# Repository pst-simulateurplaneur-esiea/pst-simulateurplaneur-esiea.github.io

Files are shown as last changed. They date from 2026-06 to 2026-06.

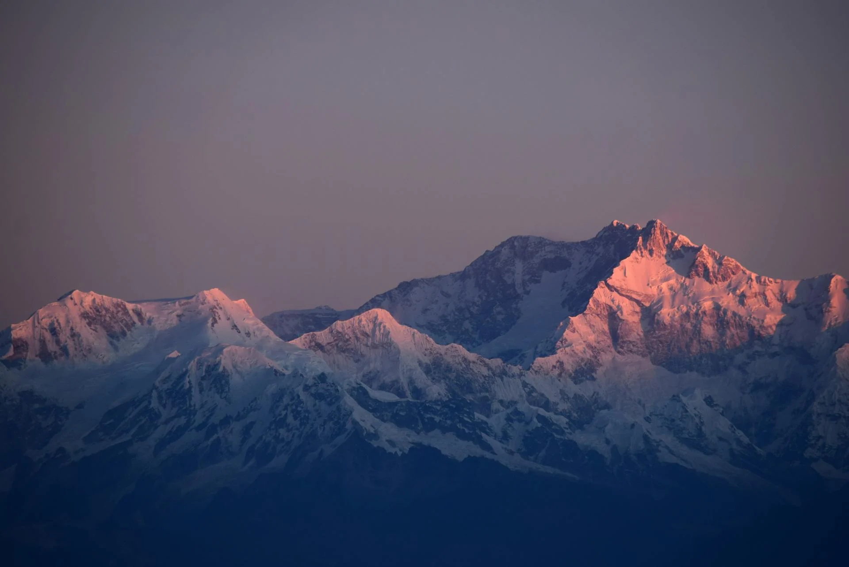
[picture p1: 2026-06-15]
image/mountain_image.jpg

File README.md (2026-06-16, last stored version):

# Glider Project Website

This is a simple, beginner-friendly website featuring a parallax scrolling effect and documentation sections.

## Files Included

- **index.html** - The main HTML structure of the website
- **style.css** - All the styling and visual design
- **script.js** - JavaScript code for the parallax scrolling effect
- **README.md** - This documentation file

## Setup Instructions

### 1. Prepare Your Images

You need to add two images to the same folder as these files:

- **glider_image.png** - Image of the glider (transparent background recommended)
- **mountain_image.jpg** - Mountain landscape for the background

**Important:** Make sure these image files are in the same directory as `index.html`.

### 2. Open the Website

Simply double-click on `index.html` to open it in your web browser.

## How It Works

### HTML Structure (index.html)

The HTML file is organized into sections:

1. **Parallax Section** - Contains the mountain background and glider image
2. **Description Section** - Project overview with black background
3. **Documentation Categories** - Two columns for different documentation types
4. **Footer** - Copyright information

### CSS Styling (style.css)

The CSS file includes:

- **General Styles** - Basic reset and font settings
- **Parallax Styles** - Positioning for the parallax layers
- **Content Styles** - Black background and text styling
- **Documentation Cards** - Styled boxes for each category
- **Responsive Design** - Mobile-friendly adjustments

### JavaScript (script.js)

The JavaScript creates the parallax effect by:

1. Listening for scroll events
2. Moving the background slower than the foreground
3. Creating a depth illusion

**Key concept:** The background moves at 50% scroll speed, while the foreground moves at 80% speed.

## Customization Guide

### Changing Colors

In `style.css`, look for these sections:

- **Background color:** `.main-content { background-color: #000000; }`
- **Card colors:** `.doc-category { background-color: #1a1a1a; }`
- **Header gradient:** `.category-header { background: linear-gradient(...) }`

### Changing Text

Open `index.html` and edit the text between the HTML tags:

```html
<h2>About the Project</h2>
<p>Your new text here</p>
```

### Adjusting Parallax Speed

In `script.js`, change these values:

```javascript
let backgroundMove = scrollPosition * 0.5;  // Lower = slower
let foregroundMove = scrollPosition * 0.8;   // Higher = faster
```

### Adding More Documentation Items

In `index.html`, copy and paste this structure within a category:

```html
<li>
    <h4>New Item Title</h4>
    <p>Description of the new item</p>
</li>
```

## Browser Compatibility

This website works on:
- Chrome, Firefox, Edge (latest versions)
- Safari (latest version)
- Mobile browsers

## Troubleshooting

**Problem:** Images don't show up
- **Solution:** Make sure image files are in the same folder as `index.html`
- Check that filenames match exactly: `glider_image.png` and `mountain_image.jpg`

**Problem:** Parallax effect doesn't work
- **Solution:** Make sure `script.js` is in the same folder and the filename is correct

**Problem:** Website looks broken
- **Solution:** Ensure `style.css` is in the same folder as `index.html`

## Tips for Beginners

1. **Use a text editor:** Visual Studio Code, Notepad++, or even Notepad
2. **Refresh the browser:** Press F5 or Ctrl+F5 to see changes
3. **Use browser DevTools:** Press F12 to inspect elements and debug
4. **Make backups:** Copy files before making major changes
5. **Test on different screens:** Check how it looks on mobile and desktop

## Understanding the Code

### What is Parallax?

Parallax is when objects move at different speeds to create a 3D depth effect. It's like looking out a car window - nearby trees move fast, distant mountains move slowly.

### How CSS Works

CSS uses selectors to target HTML elements:
- **Class selector:** `.parallax-container` (matches class="parallax-container")
- **ID selector:** `#background-layer` (matches id="background-layer")
- **Element selector:** `body` (matches all <body> tags)

### How JavaScript Works

JavaScript listens for events (like scrolling) and changes the webpage:
1. `window.addEventListener('scroll', ...)` - Watch for scrolling
2. `window.pageYOffset` - Get scroll position
3. `element.style.transform` - Move elements

## Next Steps

- Add more content to the documentation sections
- Include actual documentation links or downloads
- Add a navigation menu
- Include contact information
- Optimize images for faster loading

## License

Feel free to use and modify this code for your projects!

---

**Created:** 2026
**For:** Glider Project Documentation

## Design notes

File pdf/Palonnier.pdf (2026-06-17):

Palonnier

Équipe simulateur de planeur 2025 / 2026 | 1

# Palonnier

# Équipe PST2A 2025/2026 :

### Enzo CAFFIER Hugo LORMIER Rose NÉDÉLEC Jérémie OQUIDAM Cléo SAM-LOCK

Le Palonnier acheté et démonté : T.FLIGHT RUDDER PEDALS de ThrustMaster.

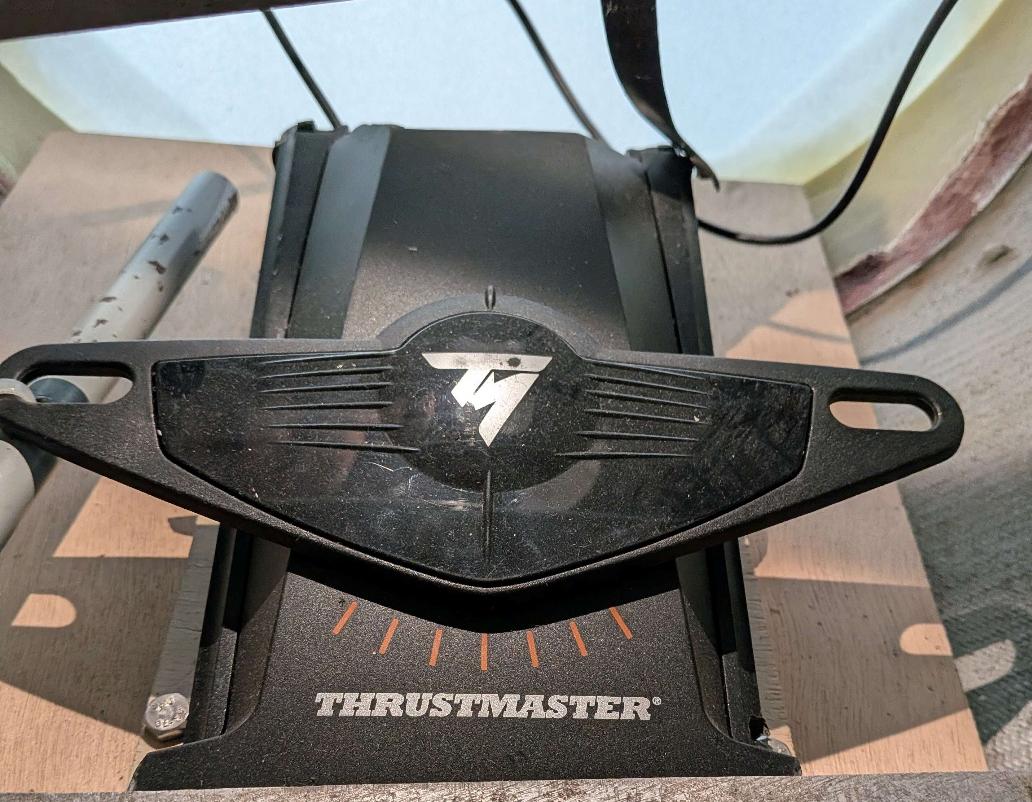
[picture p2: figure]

Ce palonnier électronique branché au hub USB dans le planeur et directement relié grâce à un tube en métal récupéré dans le planeur (en jaune) a été fixé grâce 4 vis sur une planche en bois (récupérée à l’openlab) elle-même posée sur une planche ne bois soutenue par du câble en métal accroché au planeur. Ce système est un prototype et est voué à être amélioré, un meilleur support, un système plus résistant et précis.
Ce tube en métal est directement relié et accroché au palonnier d’origine du cockpit du planeur afin de reproduire et retransmettre les mouvements des pédales du palonnier dans le palonnier électronique. Cette transmission des pédales aux palonniers est effectuée grâce aux deux câbles comme montré si dessous. Ces câbles passent dans tout le planeur jusqu’aux pédales.

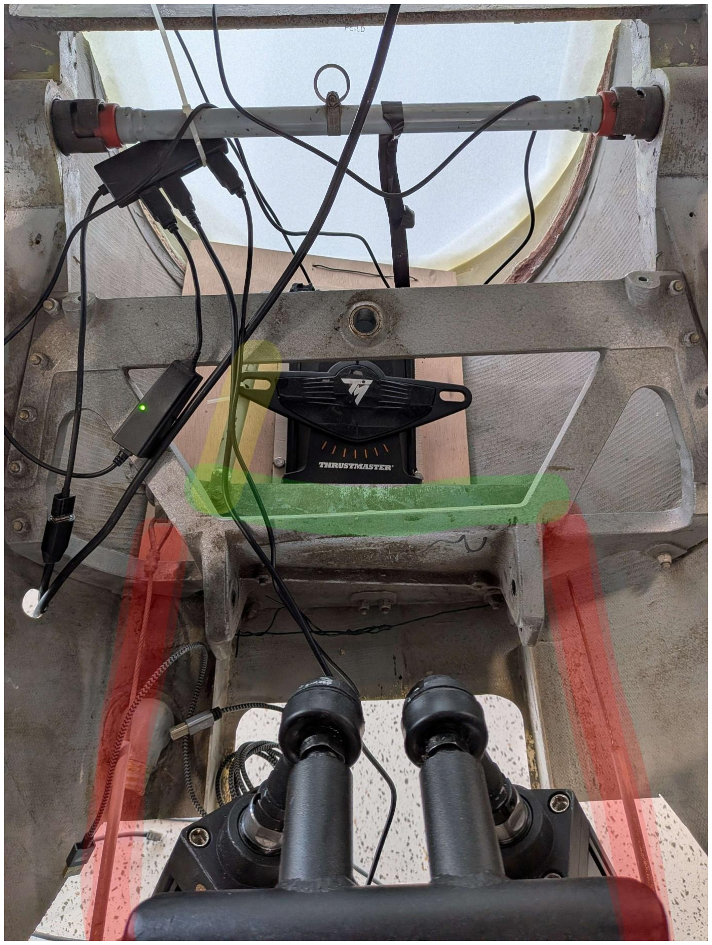
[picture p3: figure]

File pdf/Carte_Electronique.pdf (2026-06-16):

Carte_Electronique

Équipe simulateur de planeur 2025 / 2026 | 1

# Carte_Electronique

# Équipe PST2A 2025/2026 :

### Enzo CAFFIER Hugo LORMIER Rose NÉDÉLEC Jérémie OQUIDAM Cléo SAM-LOCK

La carte électronique a été récupéré sur un joystick thrustmaster TFlight Stick X qui a été démonté.

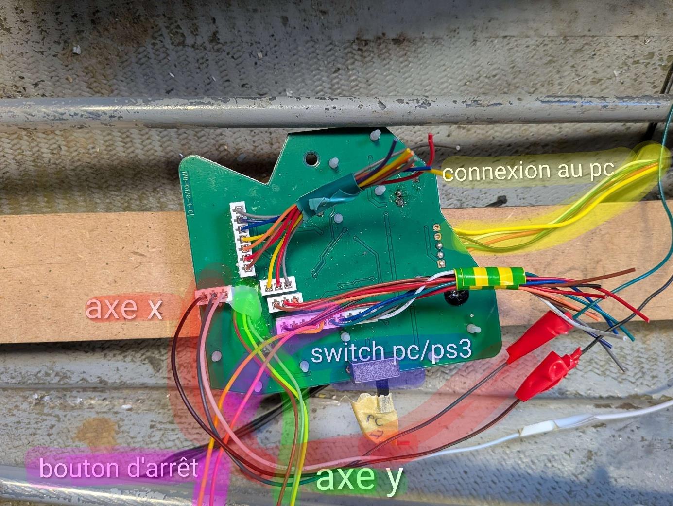
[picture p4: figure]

Le port de l’axe X :
- Cable noir : VCC+
- Cable vert : Information de -1 à 1
- Cable blanc : Terre

Le port axe Y :
- Cable rouge : VCC+
- Cable jaune : Information de -1 à 1
- Cable gris : Terre

Bouton d’arrêt, fonctionne comme un bouton d’arrêt, courant pas courant, branché aux câbles orange et jaune.
Les trois câbles précédent noir marron et rouge permettent aussi de rajouter des boutons. Le reste des pins servent pour un ancien potentiomètre (voir la photo et le composant pour plus de détails).

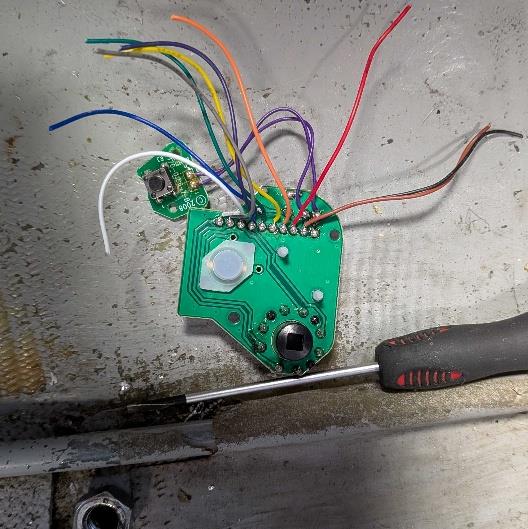
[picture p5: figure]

Switch pc/ps3 à ne pas changer afin que la carte reste compatible avec l’ordinateur branché. Switch à droite = PC, switch à gauche = PS3 : voir photo.
Sur les câbles entourés par le scotch vert, les pins sont utilisés pour des boutons en parallèles et une LED.
Câble gris : VCC+ (doit être branché)
Câbles violet, rouge, orange et marron : Boutons
Câbles jaune et bleu : permettent de brancher une LED

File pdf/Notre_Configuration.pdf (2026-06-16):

Créer configuration Flypt Mover 3.5

Équipe simulateur de planeur 2025 / 2026 | 1

# Notre configuration

# Équipe PST2A 2025/2026 :

### Enzo CAFFIER Hugo LORMIER Rose NÉDÉLEC Jérémie OQUIDAM Cléo SAM-LOCK

Pour réaliser notre configuration nous avons tout d’abord suivi les recommandations sur le site de FlyPt Mover :

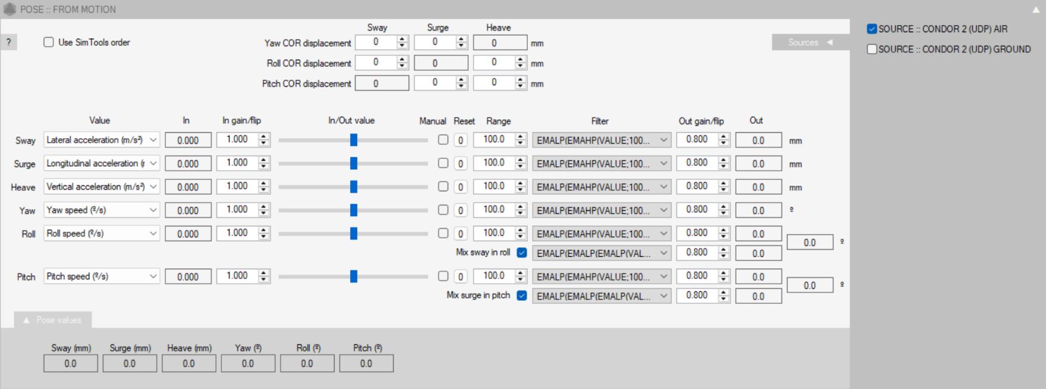
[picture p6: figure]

Pour la valeur des samples dans les filtres nous avons sélectionner les valeurs rendant un meilleur résultat après plusieurs tests, n’existant pas de formules directement disponibles pour calculer le nombre de samples optimal il est donc compliqué de justifier notre choix de manière calculatoire. Il est donc possible, voire conseillé, de trouver de meilleures valeurs à l’aide d’expériences ou de formules non disponibles actuellement.
Ainsi actuellement les filtrages sont :
Sway : emalp(emahp(VALUE,1000),300)
Surge : emalp(emahp(VALUE,1000),300) Heave : emalp(emahp(VALUE,1000),300)
Yaw : emalp(emahp(VALUE,1000),300)
Roll : emalp(emahp(VALUE,1000),300)
Mix sway in roll : emalp(emalp(emalp(value,500),500),500) Pitch : emalp(emahp(VALUE,1000),300)
Mix surge in pitch : emalp(emalp(emalp(value,500),500),500)

Cette configuration malgré son bon fonctionnement est assez vorace en terme de calculs ce qui peut causer un certain délai qui bien que minime reste dérangeant pour le pilot pouvant causer des désagréments (nausées dues à un décalage de perception entre l’oreille interne et la vision). Ce problème peut néanmoins être pallier par un ordinateur possédant une meilleure capacité de calcul.

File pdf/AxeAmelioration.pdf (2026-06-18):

Axe d’amélioration et futur du projet x

Équipe simulateur de planeur 2025 / 2026 | 1

# Axe d’amélioration et futur du projet

# Équipe PST2A 2025/2026 :

### Enzo CAFFIER Hugo LORMIER Rose NÉDÉLEC Jérémie OQUIDAM Cléo SAM-LOCK

Faire un simulateur de planeur réaliste est un magnifique projet qui reste cependant très ambitieux et compliqué à finaliser dans sa totalité en une année par des étudiants en 2eme année de cycle préparatoire. C’est donc sans surprise qu’il est facile de remarquer le manque de certaines parties au planeur, que ce soit au niveau de l’esthétisme ou à un niveau technique. En réalité ce projet n’étant pas un projet professionnel mais un projet étudiant, il reste un projet en constante évolution et amélioration. Cette section présente donc des idées dont il ne faut pas hésiter à s’inspirer mais qui ne sont que des idées qui restent à étudier plus en profondeur.

I) Idées techniques
1) Cadrans dynamiques
L’ajout de cadrans dynamiques pourraient rendre le projet plus attirant d’un point de vue extérieur, actuellement le tableau de bord est une plaque de plexiglass avec une impression UV. Condor renvoyant les valeurs des cadrans il est donc potentiellement possible de les retransmettre sur de véritables cadrans.
2) Utilisation des switchs du cockpit Le cockpit possède des switchs inutilisés, il serait donc une bonne idée de les intégrer dans la simulation, bien que leurs rôles restent à déterminer (ex : bouton restart/arrêt d’urgence pour permettre une autonomie lors de l’utilisation du simulateur).
3) Amélioration des composants existants La plupart des composants actuellement fonctionnels utilisent des mécanismes assez précaires, il est donc fortement conseillé d’améliorer ceux-ci. Par exemple, le système du retour de force du joystick fonctionne avec de simples ressorts mais le cockpit n’ayant pas de fixations adaptées il serait préférable de concevoir/trouver des pièces plus adéquates. Le système de palonnier reste lui aussi à l’état de prototype. Les composants récupérant les données du joystick sont quant à eux plus élaborés mais pourraient être remplacés par des pièces plus solides.
4) Utilisation de potentiomètres magnétiques Une alternative au remplacement par des pièces plus solides du mécanisme du joystick est l’utilisation de potentiomètres magnétiques. En effet, ceux-ci utilisent moins de place et subissent moins de frottements ce qui les rends plus durables dans le temps.
5) Retours de force dynamiques Condor étant un logiciel poussé il serait possible de récupérer les données nécessaires à la mise en place d’un retour de force dynamique (à l’aide se servomoteur par exemple), que ce soit pour le joystick, les aérofreins, le palonnier ou même les trains d’atterrissage. Ce système serait d’autant plus utile dans la perspective d’un planneur télécommandé.
6) Planneur télécommandé
Le simulateur ayant pour objectif de reproduire des sensations réalistes, il est envisageable de concevoir un planeur miniature à l’aide des précédents scans d’un véritable planeur (ce projet avait initialement pour but de concevoir le cockpit en impression 3D). Le planeur miniature serait alors dirigé à terre via le simulateur.
7) Poignée de largage
Lors des présentations le planeur démarre directement à plusieurs mètres d’altitudes pour éviter aux visiteurs la partie compliquée du décollage. Mais ce projet a pour but de réaliser une simulation réaliste il est donc nécessaire de rajouter un système permettant de détacher le planeur du câble le reliant à l’avion qui le tracte pour le décollage. Heureusement le cockpit possède d’origine une poignée de largage (poignée jaune à la gauche du tableau de bord), la mise en place d’un système ressort-bouton est donc envisageable.
8) Amélioration du système de train d’atterrissage Pour sortir/rentrer les trains d’atterrissage dans la simulation il faut actuellement enclencher un simple switch (tout à gauche sous « main ») sur le tableau de bord. Cependant dans la réalité c’est la poignée noire à la droite du poste de pilotage qui sert à contrôler les trains d’atterrissage. Ainsi, à l’instar de la poignée de largage il faudrait remplacer le bouton par un mécanisme utilisant la poignée d’origine.

II) Idées esthétiques

1) Ailettes (caches)
Le cockpit provenant d’un véritable planeur, il reste des parties visibles peu agréables à voir comme les trous initialement présents pour les ailes. La création d’ailettes qui serviraient de caches rendrait le tout plus esthétique.
2) Cache arrière
Au même titre que les ailettes un cache arrière qui couvrirait le dos du planeur permettrait de cacher l’intérieur du planeur.
3) Cache du bouton d’arrêt d’urgence Le bouton d’arrêt d’urgence situé sur le planeur possède un cache mais dû à la forme complexe de la coque ce dernier n’est pas exactement de la bonne forme.

4) Stickers ESIEA
Le cockpit est une partie d’un véritable planeur et ne possède donc pas de démarcations à l’effigie de l’ESIEA, comme des stickers ESIEA ou encore des stickers couleur bleu ESIEA à l’avant du planeur.

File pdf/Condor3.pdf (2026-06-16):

Créer configuration Flypt Mover 3.5

Équipe simulateur de planeur 2025 / 2026 | 1

# Condor 3

# Équipe PST2A 2025/2026 :

### Enzo CAFFIER Hugo LORMIER Rose NÉDÉLEC Jérémie OQUIDAM Cléo SAM-LOCK

ATTENTION : Avant de modifier quoique ce soit veuillez lire l’INTÉGRALITÉ de ce document. Ce document traite du logiciel Condor 3

1. LANCER UNE SIMULATION CONDOR 3
Condor 3 nous propose plusieurs simulations possibles chacune selon les niveaux de chacun.
- Démarrage en « Free flight » (gestion altitude, météo…)
- Démarrage en “flight school” (moins utilisé car mauvais modèle de planeur)
Démarrage d’une Free Flight :

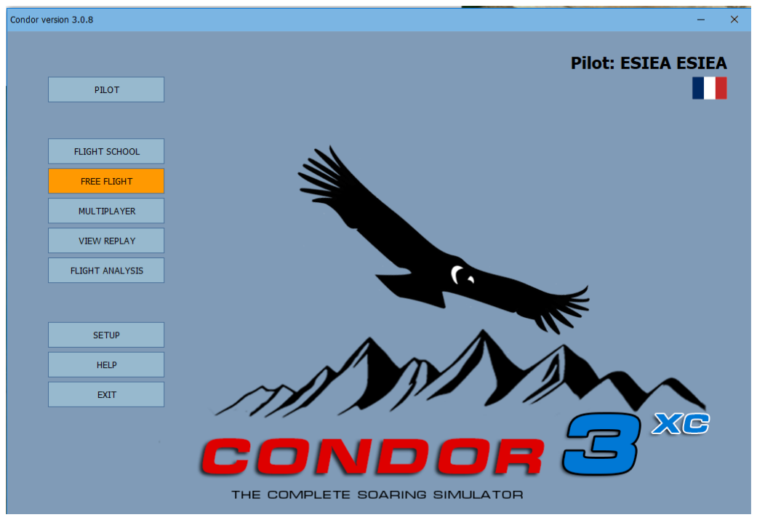
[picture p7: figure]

Voici le Menu de Condor 3 à son lancement. Cliquer sur Free Flight pour ouvrir le menu de configuration d’un vol.

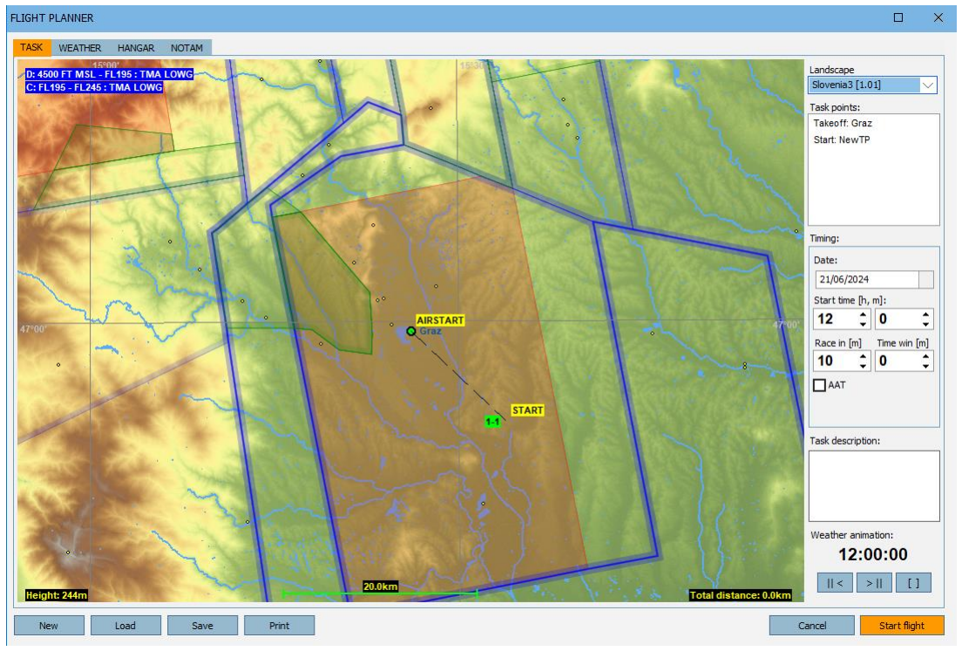
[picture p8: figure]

On arrive alors sur cette interface, ici nous pouvons sélectionner à l’aide de la souris le point de départ du vol. Takeoff :Graz ou AIRSTART comme son nom l’indique, est le point de départ dans les airs, c’est-à-dire la simulation nous fait démarrer directement en vol. Start :NewTP ou START est la piste de décollage où on démarre au sol, tracté par un avion jusque dans les airs. On se situe actuellement en Slovénie mais il est toujours possible de demander au mentor pour une autre localisation (payante).
Il est possible de changer la date et l’heure du départ (peu utile sachant qu’un planeur se pilote le jour).

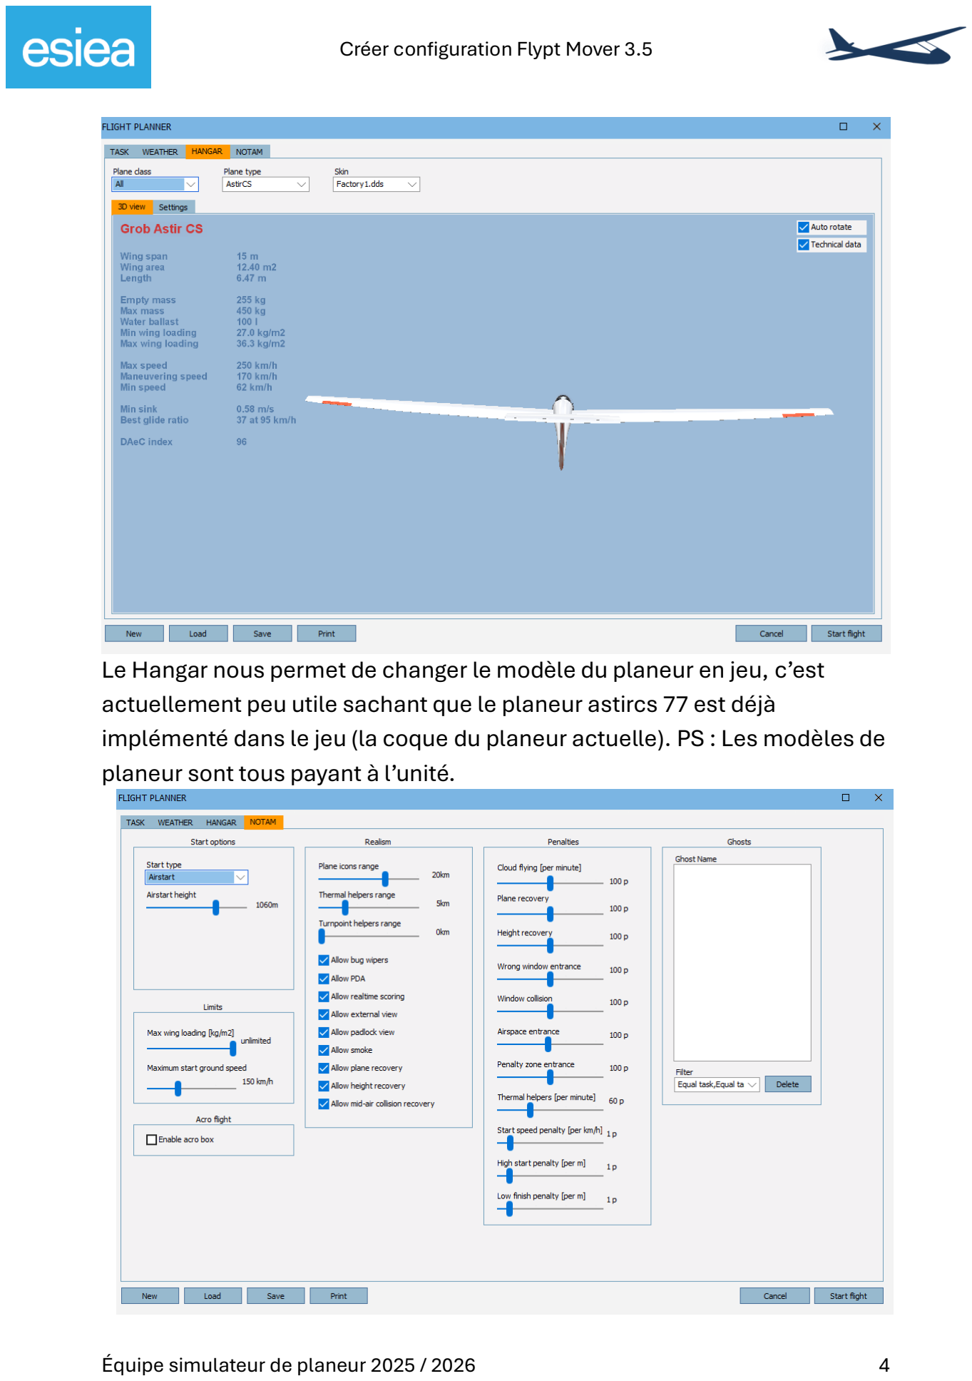
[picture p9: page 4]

Le Hangar nous permet de changer le modèle du planeur en jeu, c’est actuellement peu utile sachant que le planeur astircs 77 est déjà implémenté dans le jeu (la coque du planeur actuelle). PS : Les modèles de planeur sont tous payant à l’unité.

Le menu NOTAM permet la gestion de la simulation,
Le start type est défini par :
- Airstart : démarrage dans les airs.
- Aerotow : démarrage au sol tracté par l’avion jusqu’ au largage manuel du pilote (simulation très réaliste).
- Winch : démarrage au sol tracté par un câble (moins réaliste et plus facile)
Chaque départ a ses propres options : hauteur de départ, résistance du câble de tractage, longueur du câble ect…
Le reste des options n’ont pas été testée, libre à vous d’essayer les différents paramètres de réaliste et des pénalités

La simulation « Flight School » permet de lancer une simulation rapide mais sans aucune configuration c’est-à-dire sans le modèle de planeur astircs77, une météo classique ect…
Il faut donc sélectionner le didacticiel « TURNS » afin de pouvoir voler librement directement dans les airs.
Ce menu permet donc d’apprendre va des tutoriels à décoller, voler et se poser avec un planeur.

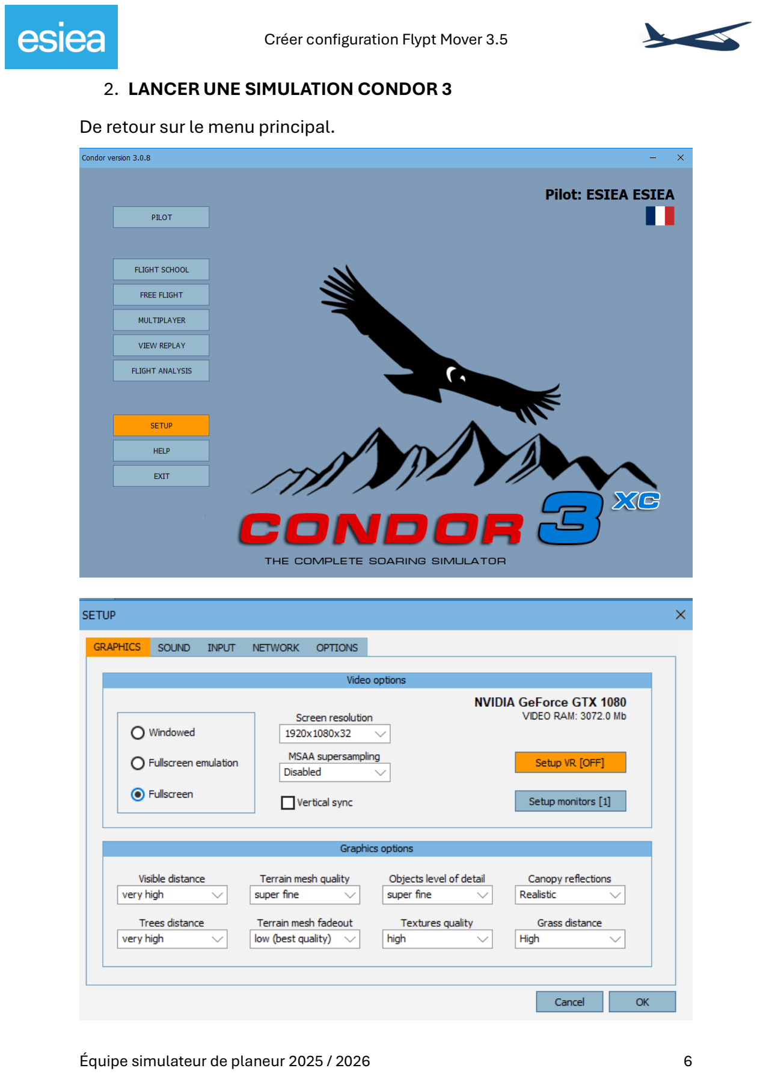
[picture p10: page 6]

2. LANCER UNE SIMULATION CONDOR 3 De retour sur le menu principal.

La configuration graphique est assez classique, pas besoin de changer la configuration originale. Le setup de la VR reste important.

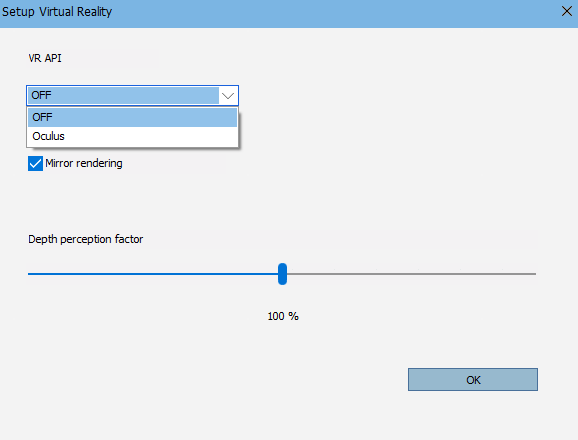
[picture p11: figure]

7
Une fois dans le menu VR, il faut sélectionner le casque branché au PC. Les paramètres « Mirror rendering » et « Depth perception factor » n’ont pas été testé. Libre à vous de compléter la documentions.

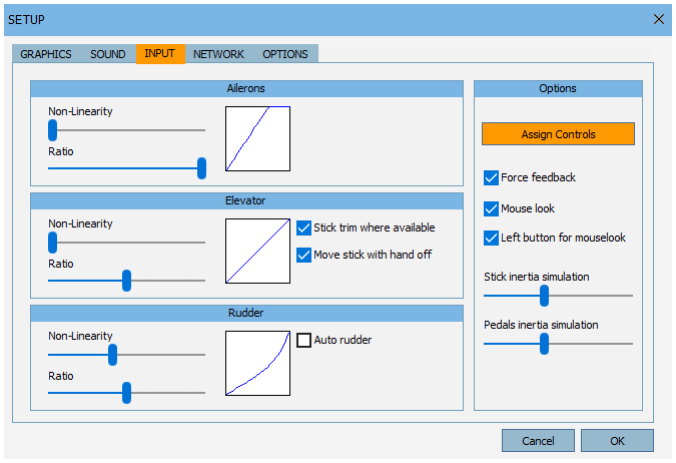
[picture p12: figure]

La section INPUT permet de modifier les axes x, y et la sensibilité du palonnier, ces axes n’ont pas été modifié car ils sont déjà adaptés et contrôlés par un logiciel plus performant : Grimlims (voir doc joystick)
On peut ensuite accéder à l’assignation des contrôles et des touches de la simulation dans « Assign Controls »

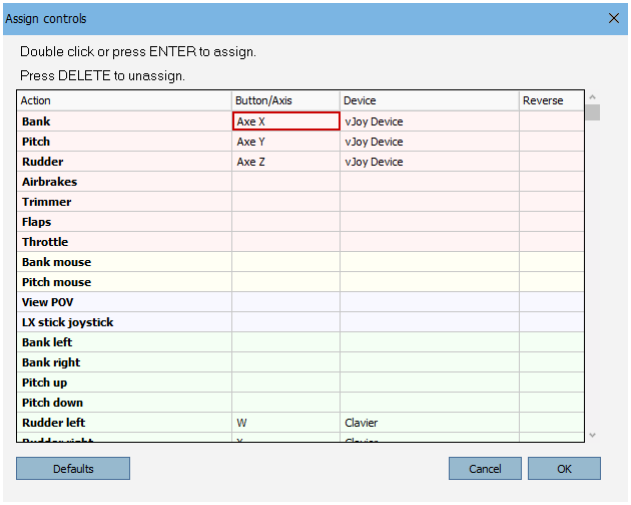
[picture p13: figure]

Les actions principales sont les 3 axes, il faut donc bouger chaque élément : le joystick dans sont axes sélectionner et le bouger dans sont axes pour l’assignation X ou Y. Et le palonnier sur l’axe Z, il faut donc bouger le palonnier pour son assignation.
A savoir qu’il faut au préalable ouvrir le joystick et le palonnier virtuels. (Voir doc joystick)
Les touches de base :
- « P » Pour lancer la simulation
- « F2 » Centrer la VR
- « F1 » Vu intérieur du cockpit VR

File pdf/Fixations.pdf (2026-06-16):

Les fixations

Équipe simulateur de planeur 2025 / 2026 | 1

# Les Fixations

# Équipe PST2A 2025/2026 :

### Enzo CAFFIER Hugo LORMIER Rose NÉDÉLEC Jérémie OQUIDAM Cléo SAM-LOCK

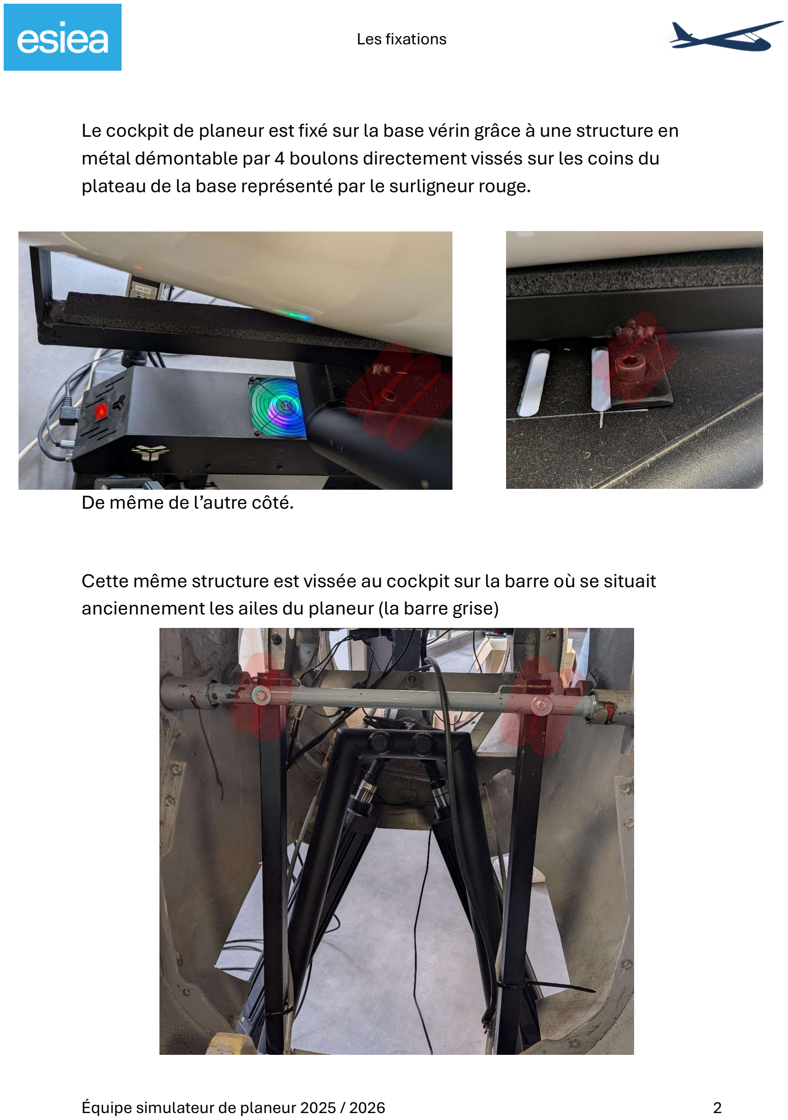
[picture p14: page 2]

Le cockpit de planeur est fixé sur la base vérin grâce à une structure en métal démontable par 4 boulons directement vissés sur les coins du plateau de la base représenté par le surligneur rouge.

De même de l’autre côté.

Cette même structure est vissée au cockpit sur la barre où se situait anciennement les ailes du planeur (la barre grise)

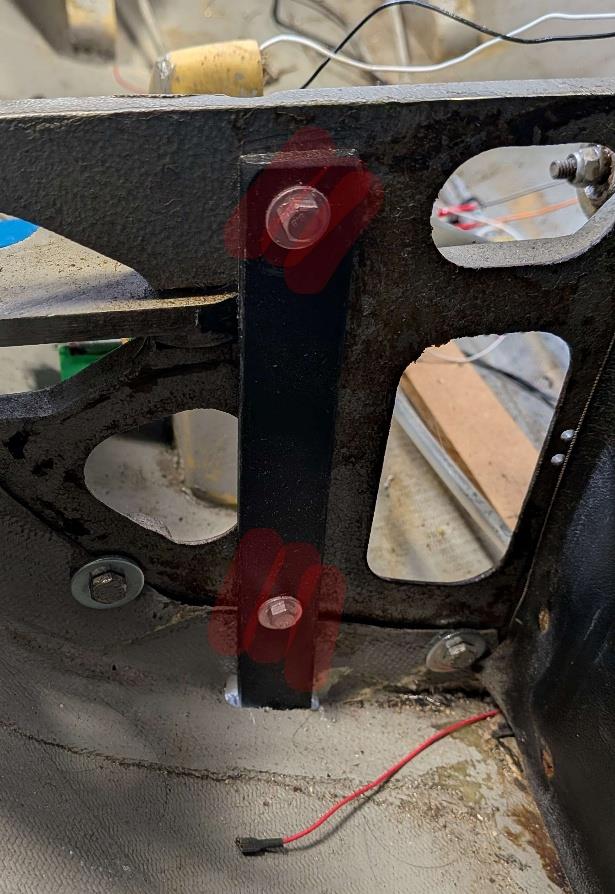
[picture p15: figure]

Et de même à l’avant sur le support du tableau de bord. (Deux vis à gauche, voir photo, et deux vis à droites) .
A savoir que les vis à l’intérieur du planeur ne doivent pas être retirées ni devisées pour plus de sécurité.

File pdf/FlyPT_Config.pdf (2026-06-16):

Créer configuration Flypt Mover 3.5

Équipe simulateur de planeur 2025 / 2026 | 1

# Configuration

De

# FlyPT Mover 3.5

# Équipe PST2A 2025/2026 :

### Enzo CAFFIER Hugo LORMIER Rose NÉDÉLEC Jérémie OQUIDAM Cléo SAM-LOCK

## CRÉER CONFIGURATION – FLYPT MOVER 3.5

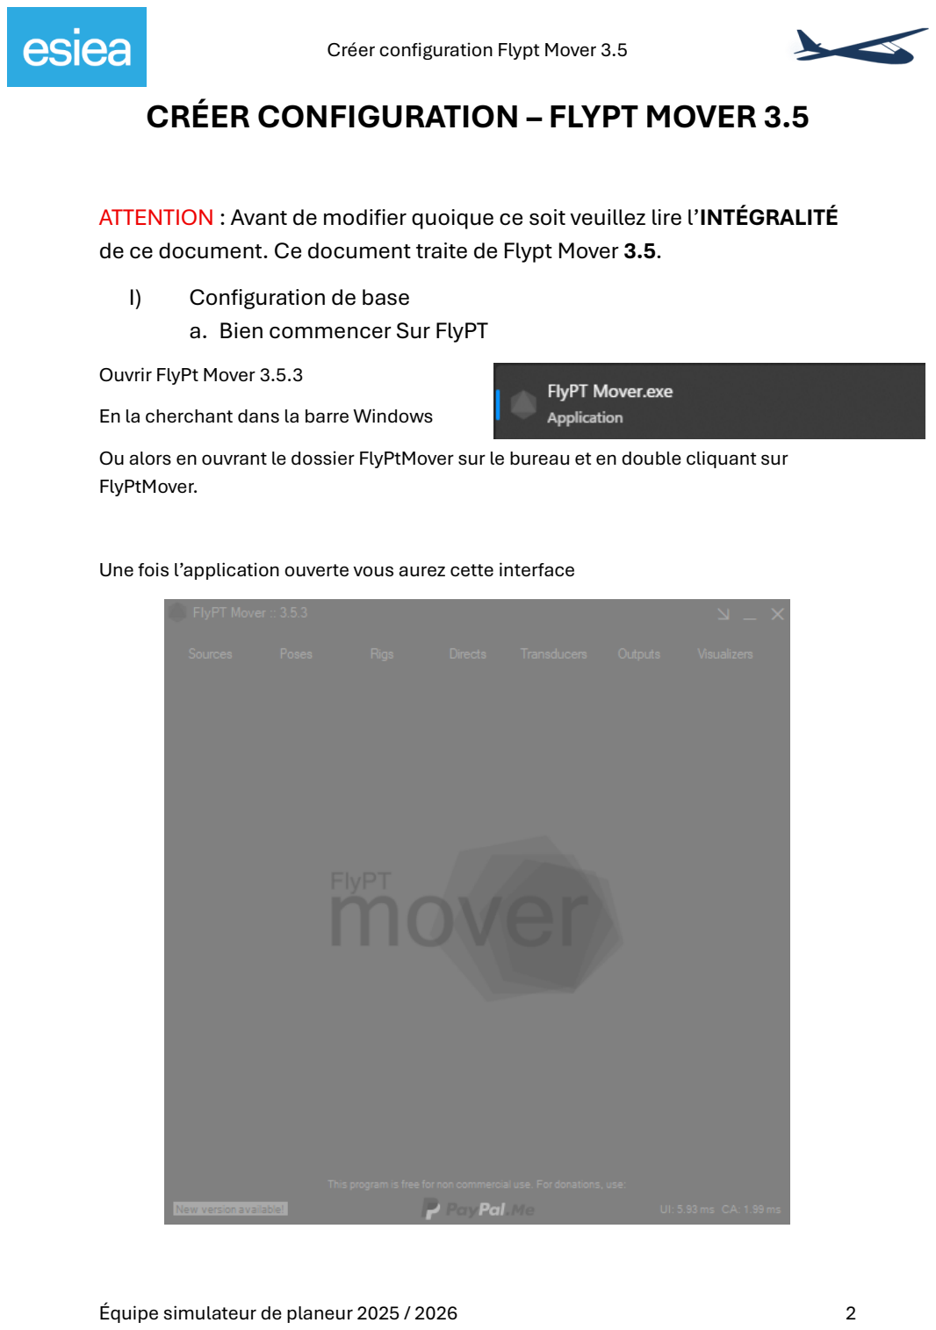
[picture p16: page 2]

ATTENTION : Avant de modifier quoique ce soit veuillez lire l’INTÉGRALITÉ de ce document. Ce document traite de Flypt Mover 3.5.
I) Configuration de base
a. Bien commencer Sur FlyPT

Ouvrir FlyPt Mover 3.5.3
En la cherchant dans la barre Windows
Ou alors en ouvrant le dossier FlyPtMover sur le bureau et en double cliquant sur FlyPtMover.

Une fois l’application ouverte vous aurez cette interface

Pour commencer à créer votre configuration faites un clic droit n’importe où sur la page :

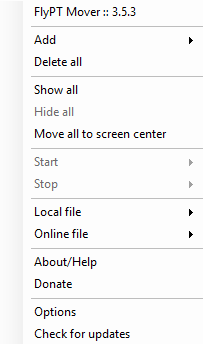
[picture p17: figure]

Pour ajouter des composants appuyer sur ADD :

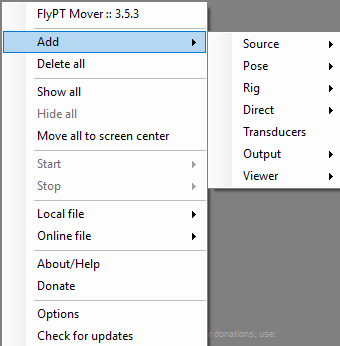
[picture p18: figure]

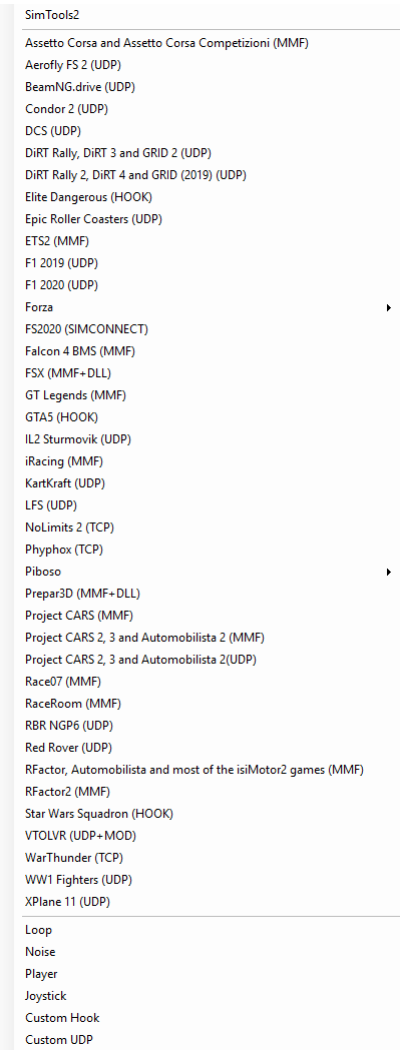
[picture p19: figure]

b. Liste des différents Composants
1. Source
Vous pouvez choisir parmi toutes les sources présentes ici.
Il existe une grande variété de logiciel déjà pris en charge mais il est également possible de prendre en entrée les joysticks ou autre.

Voici un exemple de ce que vous devez avoir après avoir ajouté une source.

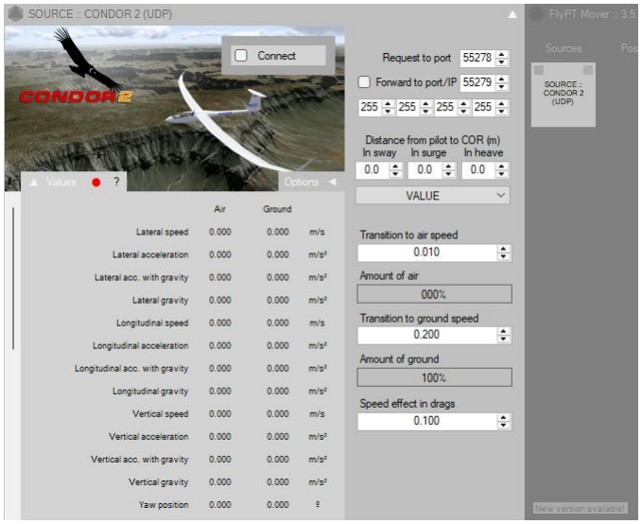
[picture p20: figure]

Nous pouvons voir ici qu’il y a beaucoup d’informations différentes qui peuvent être utile à la compréhension des étapes suivantes.

/ ! \ Pour lancer la configuration pensez à bien vérifier que le
bouton < Connect > est coché.

Pour plus d’informations sur les différentes sources et les manipulations à faire pour leur bon fonctionnement merci de vous référer à la page web des sources. (https://www.flyptmover.com/mover-3-5/sources)

2. Poses
La pose nous permet d’interpréter les informations reçus dans la source pour ensuite les transmettre au RIGS.

Vous pouvez voir ici un exemple de pose from motion.

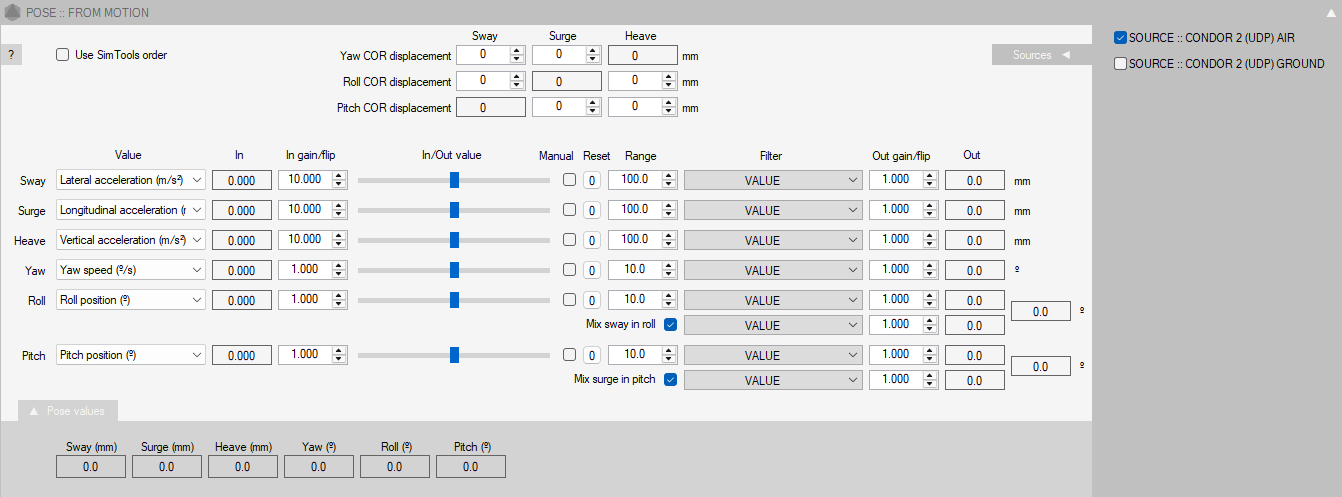
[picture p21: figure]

Il est important de sélectionner la source adéquate.

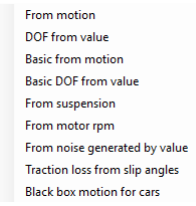
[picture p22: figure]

C’est sur cette fenêtre que nous allons pouvoir ajouter des filtres pour adoucir certains mouvements trop brusques ou enlever du bruit qui peut créer des tremblements violents.
Il est également possible de cocher la case Manual pour prendre le contrôle sur les Input pour tester les mouvements de la base Vérin.

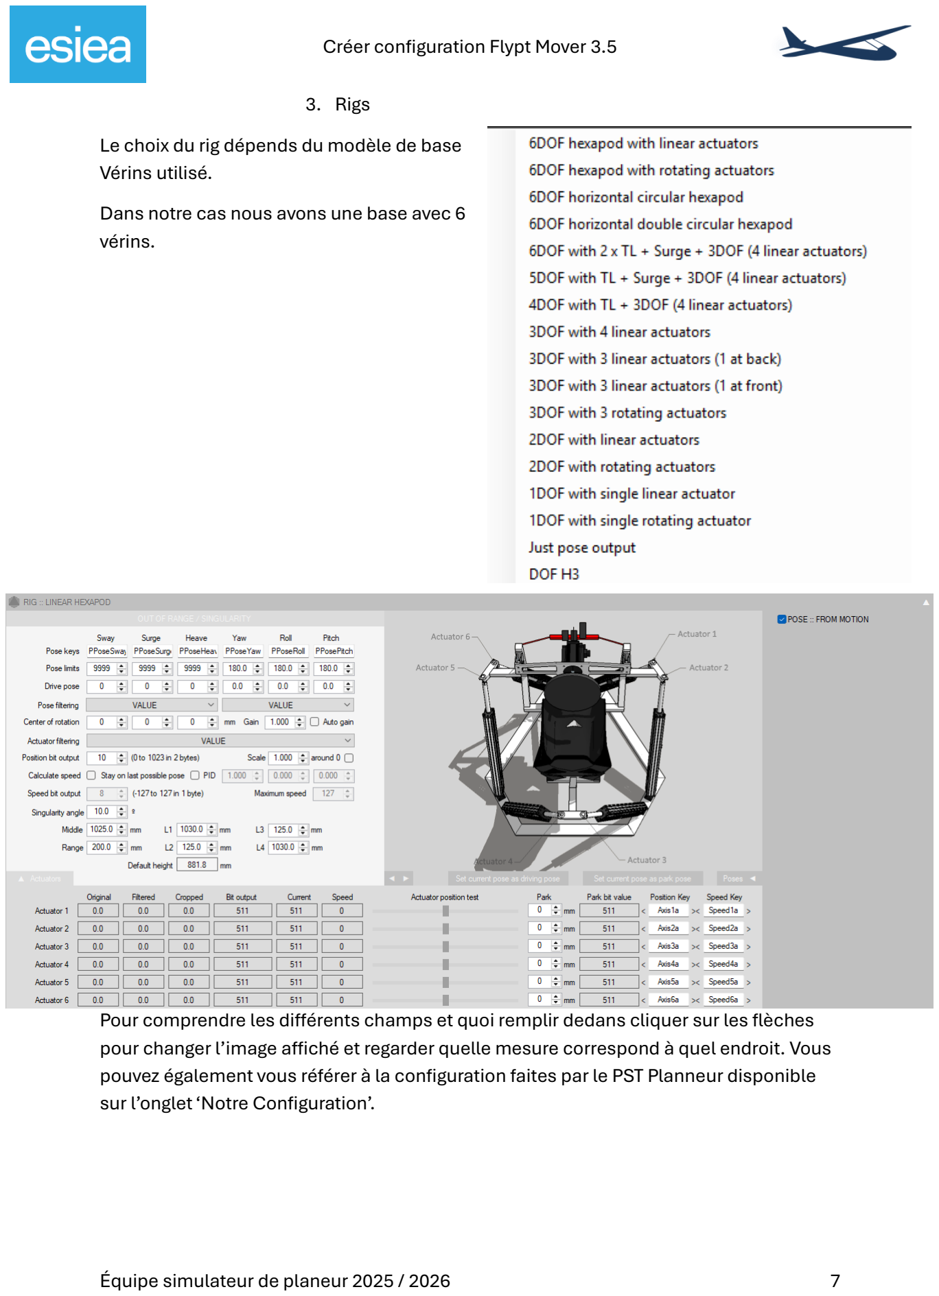
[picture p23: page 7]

3. Rigs
Le choix du rig dépends du modèle de base Vérins utilisé.
Dans notre cas nous avons une base avec 6 vérins.

Pour comprendre les différents champs et quoi remplir dedans cliquer sur les flèches pour changer l’image affiché et regarder quelle mesure correspond à quel endroit. Vous pouvez également vous référer à la configuration faites par le PST Planneur disponible sur l’onglet ‘Notre Configuration’.

4. Outputs

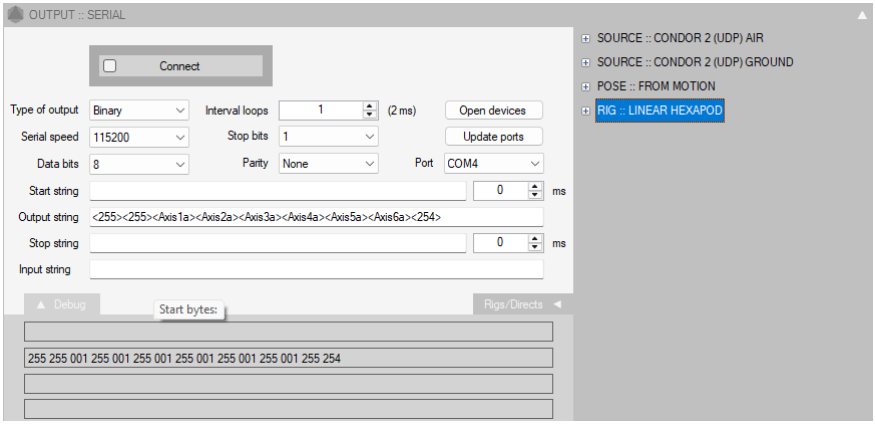
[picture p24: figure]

Pensez à bien vérifier le port sélectionné, ainsi que l’output string.

Pour plus de précision n’hésitez pas à consulter le site web qui est complet. (https://www.flyptmover.com/home)

c. Sauvegarde
Pour sauvegarder votre configuration vous avez deux options possibles.
1. Le save en .mover
Avec cette option la configuration sera
sauvegardée en <nom>.mover
Pour réouvrir la configuration sélectionner ‘Open’ puis votre ficher.

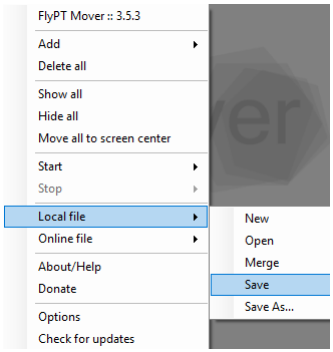
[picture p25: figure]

2. Rendre le .mover exécutable Il est possible de rendre le .mover exécutable pour lancer la configuration plus facilement. Pour cela ouvrir les ‘Options’ et ensuite cliquer sur ‘Associate *.mover files with this FlyPT Mover Executable’
Un fois cela fait vous pouvez ouvrir la configuration directement depuis le fichier stocké.


II) Panneau de filtrage (pose from motion)

1) Ouvrir FlyPt Mover.
| Allez dans le dossier FlyPt Mover 3.5.3 présent (normalement) sur le bureau, et faite glisser une config (fichier MOVER) dans l’application FlyPt Mover. Des messages d’erreurs devraient apparaître… appuyer sur continuer ça marche :)
| ATTENTION : avant de modifier la configuration assurez vous d’avoir fait une copie.
2) Le panneau de filtrage.
| Avant de créer votre propre configuration il faut comprendre comment marche le filtrage dans FlyPt Mover. Lors du démarrage de FlyPt le panneau ci-dessous devrait apparaître :


1) Sélection des sources d’où proviennent les valeurs (addition en cas de multi sélection).
2) Les valeurs après filtrages envoyées à la base vérin avec dans l’ordre la position latéral (droite-gauche), longitudinale (avant-arrière), verticale (haut-bas), rotative selon l’axe vertical, rotative selon l’axe longitudinal, rotative selon l’axe latéral

3) Réordonner les contrôles avec SimTools.
4) Pour corriger le centre de rotation s’il est trop éloigné du pilote pour éviter un décalage (voir ici (https://www.flyptmover.com/basics/center-of-rotation) pour plus d’information)
5) Les valeurs reçues (accélération, vitesse, position…) pour chaque mouvement de la base (sway, surge, roll…) (ou DOF : degree of freedom).
6) Valeurs entrantes.
7) Multiplicateurs des valeurs entrantes avant filtrage.
8) Sliders pour changer manuellement les valeurs (si base vérin connectée sélectionner 9).
9) A sélectionner pour changer manuellement les valeurs lorsque la base vérin est connecté.
10) Bouton reset à 0 pour les sliders.
11) Intervalle de valeurs pour chaque mouvement de la base les valeurs supérieures seront majorées/minorées
ATTENTION : lors de dépassements la valeur sera surlignée en rouge et ça peut amener à des mouvements parasites.
12) Les filtres pour chaque valeur.
13) Le multiplicateur pour chaque valeur après filtrage.
14) Valeurs calculées après filtrage.
Comme on peut le voir au niveau des filtres (12) du roll et du pitch il y a une coche pour l’option « mix surge in pitch » (et « mix roll in sway »), cette option permet comme elle l’indique d’ajouter les mouvements longitudinaux en mouvement de rotation autour de l’axe latéral. En effet, la base vérin ne peut pas réellement reproduire les véritables mouvements du planeur et le cockpit ne peut pas autant avancer que le planeur dans la simulation lors d’une grosse accélération. Aussi pour pallier ce problème FlyPt Mover permet de « transvaser » la force ressentie dans l’accélération longitudinale (dans le cas de mix surge in pitch » dans la force ressentie par le pilote lorsque le planeur s’incline (pitch). Ainsi, la force ressentie dans le dos par le pilote lors d’une accélération longue est maintenue grâce à l’inclinaison du cockpit (idem pour « mix roll in sway » mais avec le rolling).

III) Comment marche les filtrages ?

1) En général :


| Pour modifier le filtrage sur un mouvement (cf I.2), une fois l’onglet ouvert vous verrez apparaître des listes déroulantes auxquelles sont rattachées des valeurs (qui ont une fonction différente en fonction du filtre) et en bas un texte résumant le filtrage appliqué. Pour modifier les filtres vous pouvez le faire en modifiant le texte où depuis les sélecteurs. Nous allons ici détailler uniquement les filtres conseillés, pour plus d’information veuillez consultez la documentation en ligne de FlyPt Mover qui détaille chaque filtres (ici). (https://www.flyptmover.com/basics/filters)
| -VALUE : c’est le filtre de base, si on peut vraiment appelé ça un filtre, c’est la valeur reçue par le logiciel et elle est présente dans tous les filtres à la fin. -EMALP (ou Exponential moving average low pass) : c’est un « filtre passe-bas » pour la fréquence des valeurs, c’est-à-dire qu’il ne laisse passer que les basses fréquences faisant ainsi en sorte de rendre le signal plus lisse. ex : valeurs [1,2,3,10,2,1] →[1,2,3,3,2,1]

Le nombre rattaché au filtre ici définit le nombre de valeurs utilisées pour calculé la moyenne des valeurs reçues et déterminer quelle quantité laisser passer. En gros, plus le nombre est grand plus le signal sera lisse. Pour plus de détail voir ici. (https://www.flyptmover.com/basics/filters/sample-based-filters/emalp) -EMAHP (ou Exponential moving average high pass) : c’est le même fonctionnement que l’EMALP mais ici on laisse passer les hautes fréquences, amplifiant les pics. En gros plus le nombre associé au filtre est grand plus les pics préservés sont lisses.
Pour plus de détails voir ici. (https://www.flyptmover.com/basics/filters/sample-based-filters/emahp)
2) Les filtres conseillés
On distingue trois types de mouvement : les mouvements linéaires (sway, surge, heave), les mouvements rotatifs (yaw, roll, pitch) et les mouvements de coordination (« mix sway in roll », « mix surge in pitch »). Chaque type de mouvement à un filtrage conseillé :


Pour résumer :

1. Les mouvements linéaires utilisent généralement un EMAHP suivi d’un EMALP : EMALP(EMAHP(VALUE,x),y) et il est conseillé de sélectionner l’accélération en valeurs reçues (voir I.2). -Pour avoir plus de mouvement augmentez x.
-Pour avoir que les mouvements soient plus souples augmentez y.
2. Les mouvements rotatifs fonctionnent avec le même principe sauf qu’il est ici conseillé de sélectionner la position si la base peut effectuer un mouvement de 360° autour de l’axe choisit, sinon il vaut mieux choisir la vitesse. La base vérin initiale ne pouvant pas pivoter de 360° sur aucun axe il est préférable de sélectionner la vitesse.
3. Les mouvements de coordination servent à compenser le manque de mouvements selon un axe et ne doivent donc pas être perçus par l’utilisateur. Il est donc conseillé de mettre un EMALP suivi d’un autre EMALP (et si ce n’est pas suffisant encore un autre): EMALP(EMALP(VALUE ou EMALP(VALUE,x),x),x). Pour plus de souplesse augmentez x. De plus, il vaut mieux que :
-le pitch augmente de manière souple quand le surge revient à zéro, de façon à ce que l’utilisateur ne perçoive pas le changement.
-le surge revienne à zéro de manière douce.
-des petites variations d’accleration du surge (resp. du sway) autour d’une valeur (pour tester vous pouvez bouger le slider sur un petit intervalle) ne fasse pas varier le pitch (resp. le roll).

Voilà pour les généralités vous êtes maintenant capable de créer votre propre configuration avec les filtrages nécessaires, pour plus de détails concernant la configuration actuellement en place référez-vous à la documentation « notre configuration ».

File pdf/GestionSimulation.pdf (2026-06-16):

Gestion de la simulation

Équipe simulateur de planeur 2025 / 2026 | 1

# Gestion de la simulation

# Équipe PST2A 2025/2026 :

### Enzo CAFFIER Hugo LORMIER Rose NÉDÉLEC Jérémie OQUIDAM Cléo SAM-LOCK

I)Démarrer la simulation
1) Branchement
Pour démarrer la simulation il faut tout d’abord s’assurer d’avoir brancher tous les composants :
A la base vérin il faut brancher :
-l’ordinateur
-l’alimentation
-bouton d’arrêt d’urgence/ contrôleur de puissance (molette)

A l’ordinateur il faut brancher :
-la base vérin
-le bouton d’arrêt d’urgence
-périphériques (souris, clavier, écran)
-différents câbles HDMI reliés aux composants du planeur (palonnier, joystick…)
2) Lancer FlyPt Mover et Condor
-Ouvrir le dossier FlyPT Mover 3.5.3, puis faire glisser votre configuration (.Mover) dans le logiciel (.exe)
-Lancer Condor


3) Démarrer la base vérin
-Mettre en position ON le bouton d’alimentation situé sur la base vérin. -Appuyer en prolonger sur le bouton « start » situé sur le boitié avec la molette de puissance et le bouton d’arrêt d’urgence jusqu’à entendre un « bip », la base devrait légèrement se soulever.

-Appuyer sur les boutons « connecter » de FlyPt Mover. Pour y accéder cliquer sur les deux modules de FlyPt Mover ci-dessous :


Les deux fenêtres ci-dessous devraient s’ouvrir :


Sélectionner le port auquel est brancher la base vérin puis cliquer sur « connecter »

La base vérins devrait se lever puis redescendre, parcourant toutes les plages de puissances.
La molette permet ensuite de régler la puissance voulue (10-99), il est cependant conseillé de ne pas mettre la puissance au-delà d’un certain seuil sur certaine configuration.
Démarrer ensuite un vol Condor (voir la section dédiée à Condor), notamment la partie sur la VR.

II) Éteindre la simulation
Pour éteindre la simulation le principe est le même que pour la démarrer mais dans l’autre sens :
-Déconnecter la base vérin et Condor de FlyPt Mover.
-Appuyer de manière prolonger sur le bouton « start » présent sur le boitier avec le bouton d’arrêt d’urgence et la molette de réglage puissance, vous devriez entendre un « bip » et la base devrait légèrement s’affaisser (ATTENTION : cette étape est cruciale pour éviter tout accident au démarrage)
-Éteindre la base vérin avec le bouton d’alimentation au niveau de la base

Condor et FlyPt Mover n’ont pas forcément besoin d’être fermé pour éteindre la simulation.

III) Arrêt d’urgence ou mise en sécurité de la base
La base peut, en cas de surcharge des vérins ou si le bouton d’arrêt d’urgence se mettre en sécurité, ceci peut se manifester par un vérin bloqué dans une certaine position ou bien si l’arrêt d’urgence est enclenché par une remise à la position d’origine de la base.
Pour redémarrer la base il n’est pas nécessaire d’aller jusqu’à éteindre la base complétement, il est dans la majorité des cas suffisant de déconnecter-reconnecter la base. Si toutefois cela ne marche toujours pas, notamment lorsqu’un vérin se bloque, il faut alors éteindre complétement la base vérin et la relancer.

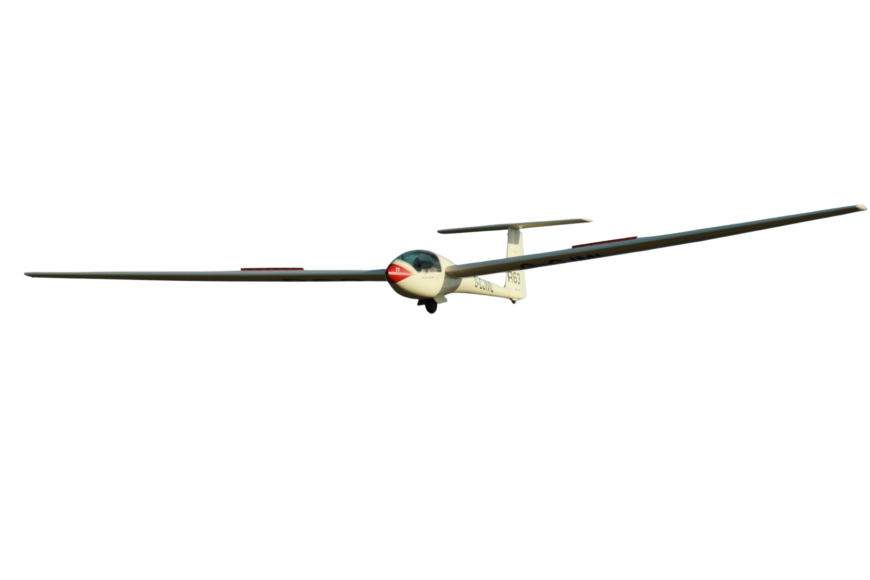
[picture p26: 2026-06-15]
image/glider_image.png

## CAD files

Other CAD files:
model3d/rond-bouton.f3d
model3d/support-potent-aero-petit.f3d
model3d/support_aero-frein.f3d
model3d/support_axe_x_proto2.f3d
model3d/support_axe_y_proto2.f3d
model3d/support_tige_metal.f3d
model3d/tige_capteur_axe_x_y.f3d
